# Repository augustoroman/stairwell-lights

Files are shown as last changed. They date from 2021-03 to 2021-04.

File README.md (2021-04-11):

# Motion-Activated Stairwell Lights

This project uses [addressable LED
strips](https://components101.com/displays/neopixel-led-strip), two [PIR motion
sensors](https://learn.adafruit.com/pir-passive-infrared-proximity-motion-sensor),
and [a microcontroller](https://www.sparkfun.com/products/13231) to make some
motion-activated stair lighting with some cool light-up animations.

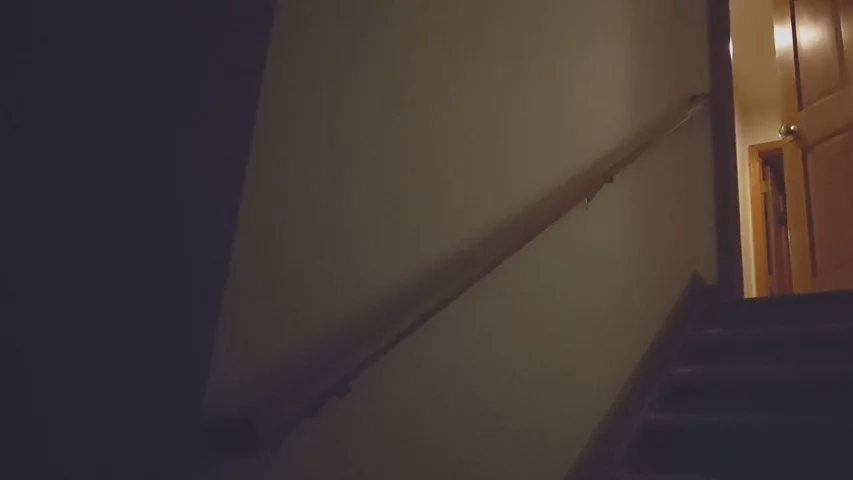
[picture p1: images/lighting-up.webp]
Lighting up


# How it works

The basic setup is:

Overview Schematic

The stairwell turns 90°, so there are two LED strips: the upper and the lower.
Similarly, there are two PIR motion sensors: the upper (looking upwards) and the
lower (looking downwards).

The LED strips and motion sensores are plugged into an ESP8266 housed in a 3D
printed box:

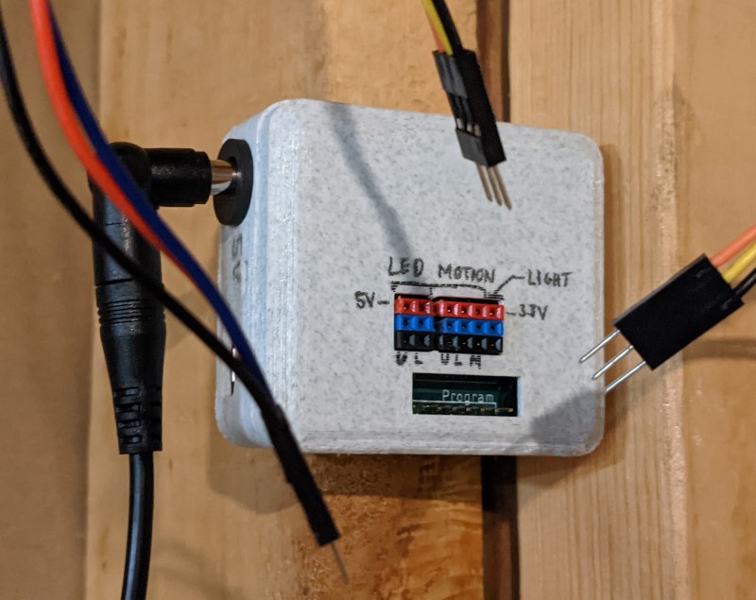
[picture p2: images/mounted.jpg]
Mounted controller box


Within the box is the microcontroller along with a simple custom PCB that routes
the wiring:

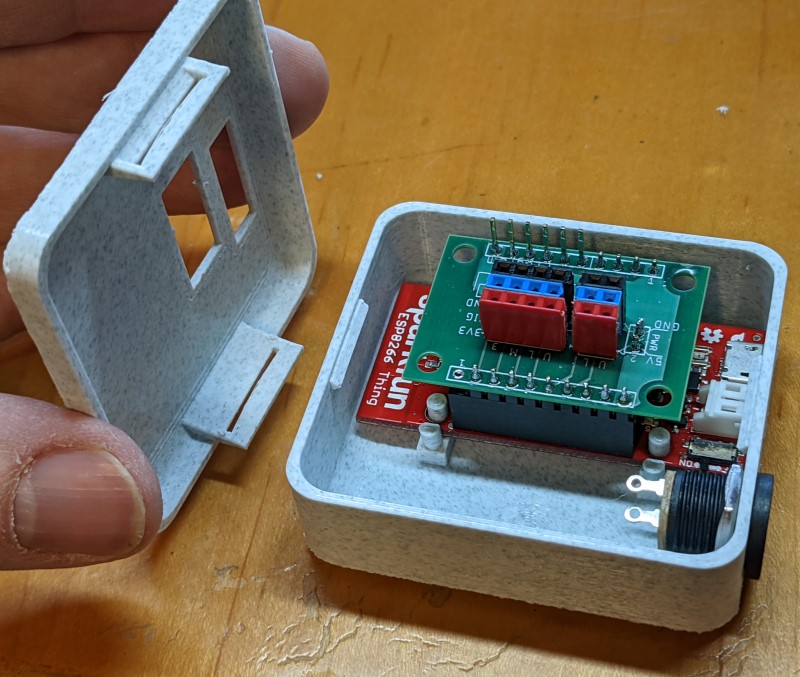
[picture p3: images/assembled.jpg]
Inside controller box


The custom PCB by itself:

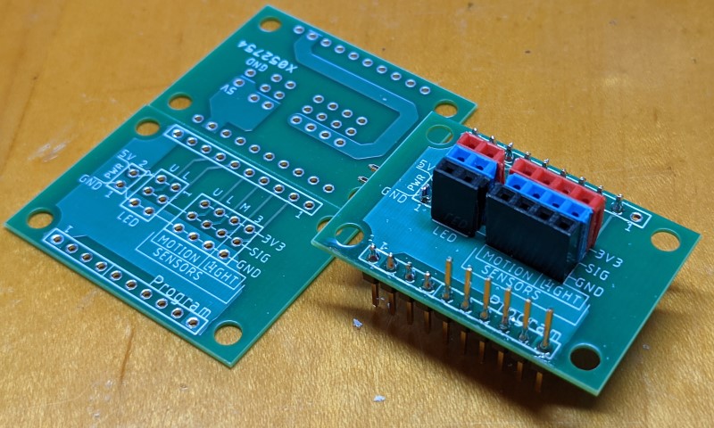
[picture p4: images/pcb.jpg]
Custom PCB


# Materials

### Core Materials

* A 5m string of **WS2812B lights** with an adhesive backing
  [[Amazon](https://www.amazon.com/gp/product/B01CDTEJBG)] <br> The important
  characteristics of this strip are:
  * WS2812B lights are relatively cheap but still individually addressable so
    that each LED is individually controlled.
  * 5V lights makes it easier to integrate with the microcontroller.
  * I used 60 LEDs/m density to balance smooth lighting with power usage.
    Probably 30 LEDs/m would work just about as well.
  * They have adhesive backing so I can just stick them straight to the bottom
    of the handrail.
* **PIR sensors** (2x) [[Amazon](https://www.amazon.com/gp/product/B08PVB7VHQ/)]
  <br> The important characteristics of these are:
  * They come with connector pins already (easy to integrate) and are about the
    size I wanted.
  * They are open-collector that ground the sensor line, so they work with 5V or
    3.3V.
  * They have 3 - 5m range, which worked well for my stairwell.
* An **ESP8266 microcontroller** [[Sparkfun](https://www.sparkfun.com/products/13231)]
  <br> I happened to have one of these microcontrollers lying around, but most
  Arduino or ESP boards should work. The important characteristics are:
  * It has at least 4 digital I/O pins.
  * It automatically handles 5V -> 3.3V conversions.
  * It's small and fairly cheap.
  * It has Wifi built-in, which is great for upcoming features I want to add.
  * It also has analog inputs that I want to use for upcoming features (a light
    sensor).

### Custom items

Some custom manufactured items:

* [A PCB](./connector-pcb) that allows simple wiring between the ESP8266 pins and the wiring to the
  LED strips and sensors.

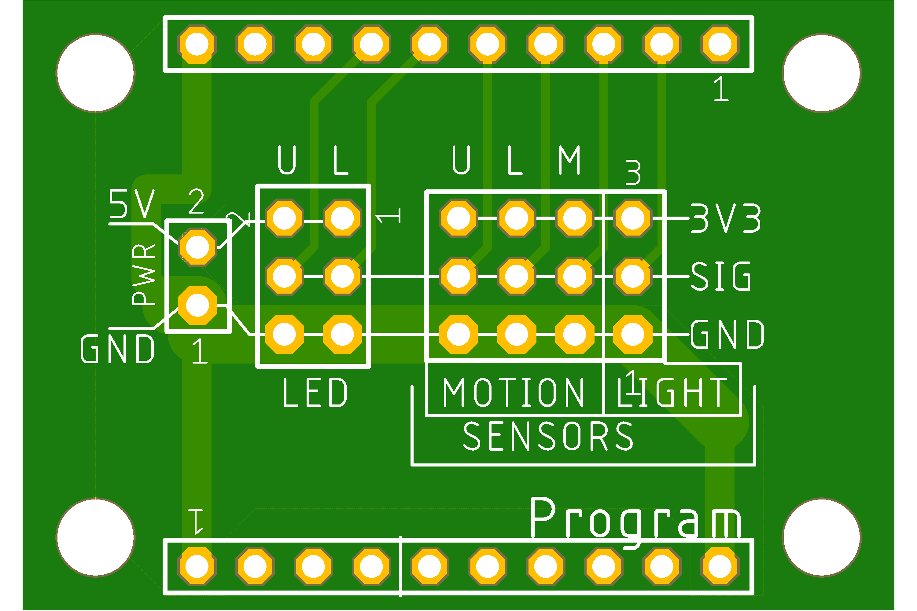
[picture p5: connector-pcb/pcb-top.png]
  
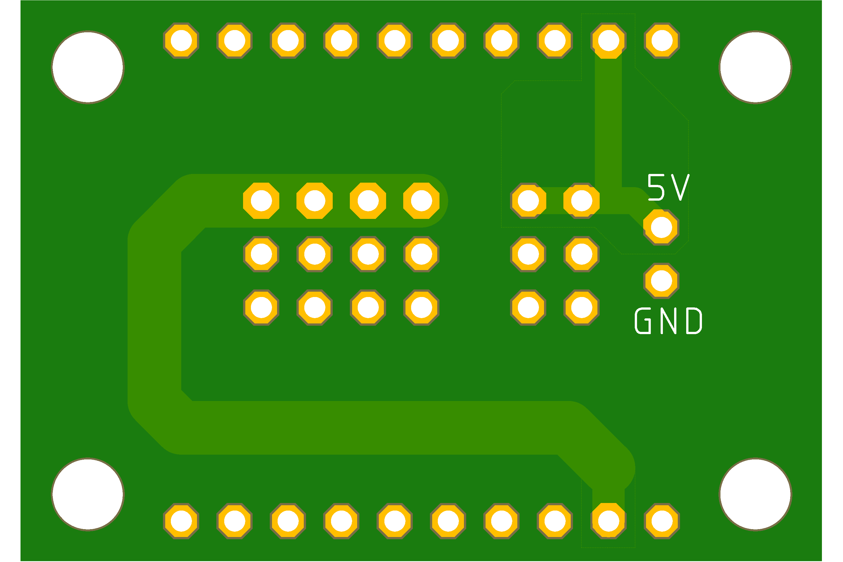
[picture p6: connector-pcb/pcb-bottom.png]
  

  This was manufactured using basicpcb.com which can create this 1.5" x 1.05"
  board for only ~$2.50 each! With a min quantity of 3, that's only ~$8 for the
  board (including shipping!).

* Several [3D-printed items](./3dprint): case ([top](./3dprint/case-top.stl),
  [bottom](./3dprint/case-bottom.stl)) and [PIR sensor
  mount](./3dprint/pir-holder.stl).

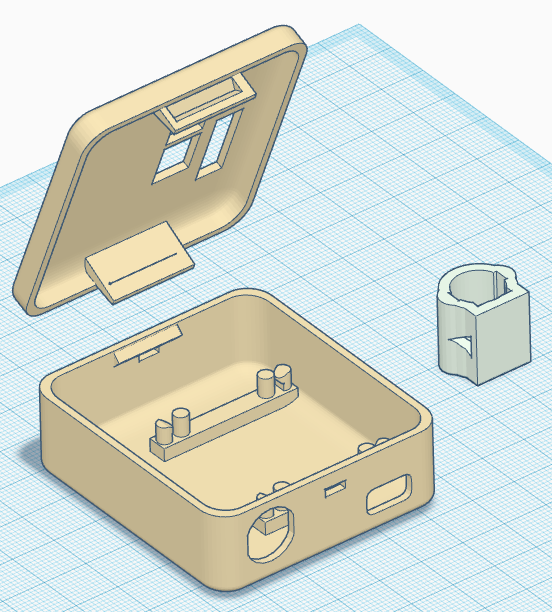
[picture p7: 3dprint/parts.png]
  

### Miscellaneous Materials

Those are the core of the whole setup, but there's lots of additional things I
needed to actually complete the setup:

* **Colorful headers** [[Adafruit](https://www.adafruit.com/product/4160)] <br>
  I used these nice colorful headers so it's obvious which way to connect the
  strips since I used plain headers instead of polarized connectors. Probably I
  should have used polarized connectors, but that would probably require a PCB
  change.
* A panel-mount **DC barrel jack connector**
  [[Adafruit](https://www.adafruit.com/product/610)]
* **LED strip connectors** [[Amazon](https://www.amazon.com/gp/product/B08NX8TN8C)]
  <br> I originally tried soldering wires to the LED strips, but changed from
  the small-gauge hookup wire to the thicker 20-gauge wire and used these
  connectors instead. I glue-gunned the connector to the bottom of the railing.
* A **5V DC power supply**. The current software draws 0.25A idle and 0.5A
  maximum current draw from the power supply (2.5W max), so this [5W power
  supply](https://smile.amazon.com/dp/B08Q38QMFD) or this [10W power
  supply](https://smile.amazon.com/dp/B0863J9RLW) should work fine and provide
  plenty of buffer.  I'm currently using [a generic
  supply](https://www.amazon.com/gp/product/B078LSVVTB) for development.
* **20 AWG solid-core hookup wire** to connect the LEDs
  [[Amazon](https://www.amazon.com/gp/product/B083DNGSPV)] <br> The LEDs can use
  a surprising amount of power (up to 90W for the whole strip!!), and really
  thin-guage wire may melt. The program I have runs the LEDs only at very dim
  settings, so we're not maximing out the power draw and the 20 gauge wire
  should be sufficient.
* **22 AWG hookup wire** to connect the motion sensors
  [[Amazon](https://www.amazon.com/gp/product/B088KQFHV7)] <br> You can use the
  20 gauge wire too, but I had this thinner wire around for the low-power
  sensors.
* A **crimper and connectors**
  [[Amazon](https://www.amazon.com/gp/product/B07R1H3Z8X)] to make clean
  connections to/from the microcontroller. <br> I used the XH-2A connectors for
  power with short 18-AWG wire, but that was a tight fit.

# Changes I would make if I did this again

- [ ] I'd use a board-mounted DC jack instead of a panel-mounted one and modify
  the PCB to use that. That means I'd have to extend the board a bit (a few more
  $), but connecting the board to the panel-mount DC jack was a pain.
- [ ] I'd probably space out the connectors some and use polarized connectors.
- [ ] The 3D printed case could use quite a bit of tweaking to tight up the
  tolerances.
  - [x] The opening for the programming headers was shifted to the side.
    I've fixed that in the tinkercad version but not the STLs here.
  - [ ] The snaps that hold the board are too loose -- the board snaps in
    tightly but then wiggles around.
  - [ ] The top and bottom fit together too loosely.
  - [ ] I'd try to 3D print labels on the case directly, maybe even try to
    change filament colors so they look nice. If not changing colors, at least I
    could color the raised labels.

# Features I want to add to the software

- [ ] Add wifi control and save setting to EEPROM
  - [ ] On initial boot (or when it cannot connect to wifi), start an access
    point and webserver and allow configuring the board with wifi creds.
  - [ ] When connected to wifi, allow configuring the length of each LED string
    rather than having that hard-coded.
  - [ ] Track history of when the lights were triggered and provided via the web
    server so I can be sure it's not triggering spuriously all night long.
  - [ ] Fun: Add LED test mode where a slider control turns on a single LED and
    you can watch it slide back and forth.
  - [ ] Control the "on" color of the lights via the web server. Can
    bright/dim/colorize the lights this way, but watch out! Making the LEDs too
    bright might draw too much power.
- [ ] Add [a light sensor](https://www.sparkfun.com/products/8688) to disable
  the lights when it's already bright. The connection is easy and the connector
  board already planned for this, but picking thresholds is hard. I want the web
  server up and running first.
- [ ] Maybe add a middle motion sensor that looks at the landing. Right now the
  landing is not visible from either the upper or lower sensors, but it's not a
  problem.

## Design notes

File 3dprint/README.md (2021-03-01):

# 3D printed parts

I designed and printed many test parts for this project but ultimately used 3 of
them:

* A holder for the PIR sensors I used.
* The top and bottom case for the microcontroller and DC jack.

In this directory I've included the STL files for these parts. The [original
design was done in tinkercad](https://www.tinkercad.com/things/i8FOYjX7VH2).

Parts
Assembed

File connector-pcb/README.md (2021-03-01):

# Connector PCB

This PCB was designed to plug into a [SparkFun ESP8266
Thing](https://www.sparkfun.com/products/13231).





It was designed in the [free version of Autodesk's Eagle
CAD](https://www.autodesk.com/products/eagle/free-download).

I had this manufactured by basicpcb.com which was very cheap and fast: it cost
about $15 since I paid an extra $8 for quick shipping and I received the board
in 8 calendar days.

Included is the original [stairwell.brd](./stairwell.brd) file, but I've also
included the [gerber zip file](./stairwell_2021-02-15.zip) that can be directly
uploaded to basicpcb.

The board dimensions are 1.5" x 1.05".

Here's the file to layer mapping:

file                   | layer
-----------------------|-------------------
copper_bottom.gbr      | Bottom Copper
copper_top.gbr         | Top Copper
drill_1_16.xln         | NC Drill
gerber_job.gbrjob      | Drawing/Other
profile.gbr            | Drawing/Other
silkscreen_bottom.gbr  | Bottom Silkscreen
silkscreen_top.gbr     | Top Silkscreen
soldermask_bottom.gbr  | Bottom Soldermask
soldermask_top.gbr     | Top Soldermask
solderpaste_bottom.gbr | Bottom Solderpaste
solderpaste_top.gbr    | Top Solderpaste

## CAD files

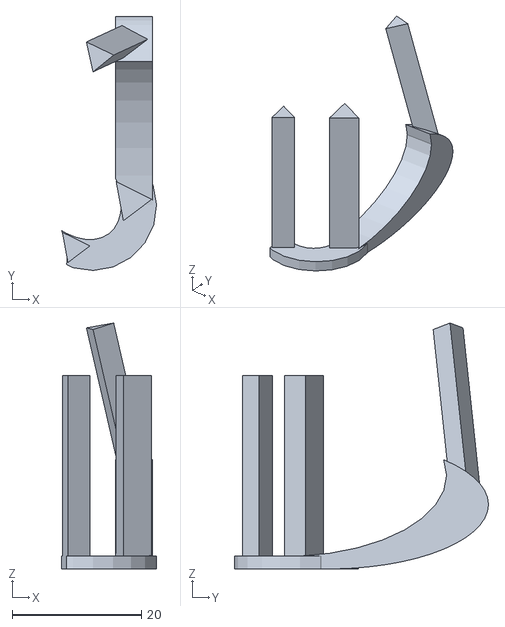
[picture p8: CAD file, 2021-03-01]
3dprint/pir-holder.stl
14.7 x 39.3 x 38.1

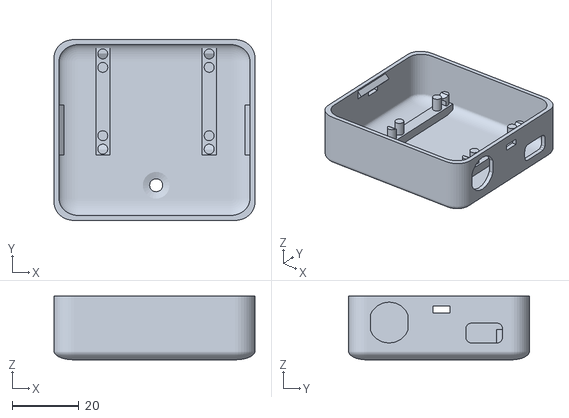
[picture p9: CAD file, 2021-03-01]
3dprint/case-bottom.stl
60.0 x 54.0 x 19.0

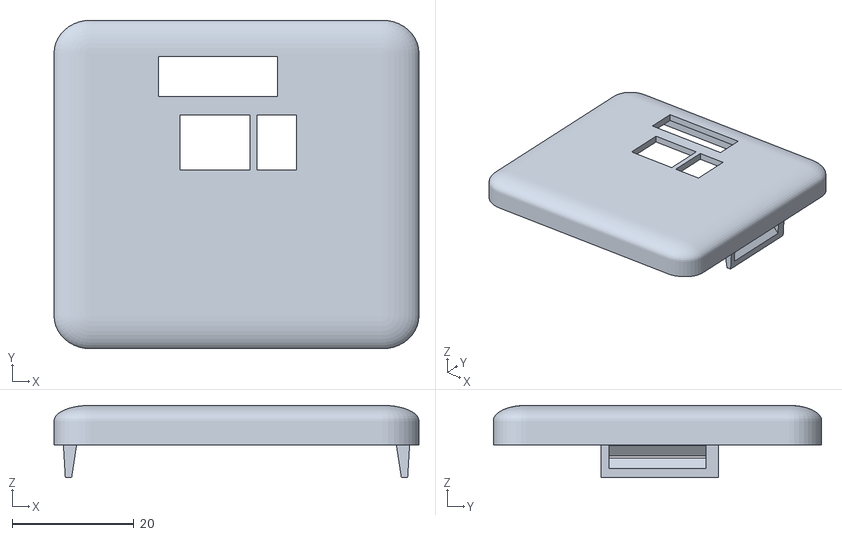
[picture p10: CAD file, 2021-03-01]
3dprint/case-top.stl
60.0 x 54.0 x 11.9

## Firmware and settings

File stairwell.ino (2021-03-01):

#include <FastLED.h>

const int LOWER_STRIP_PIN = 4;
const int UPPER_STRIP_PIN = 0;
const int LOWER_STRIP_COUNT = 73;
const int UPPER_STRIP_COUNT = 167;
const int NUM_LEDS = UPPER_STRIP_COUNT + LOWER_STRIP_COUNT;

const int LOWER_MOTION_PIN = 12; // Pin connected to motion detector
const int UPPER_MOTION_PIN = 13; // Pin connected to motion detector

// LED is pin 13 on the blackboard, but pin 5 on the thing
// const int BOARD_LED_PIN = 13; // Blackboard LED pin - active-high
const int BOARD_LED_PIN = 5; // Thing LED pin - active-high

const int STEP_MS = 10;
const int STEP_OVERHEAD = 7;
const int TIMEOUT_MS = 10000;
const int TIMEOUT_STEPS = TIMEOUT_MS / (STEP_MS + STEP_OVERHEAD);
const int DIM_MS = 5000;
const int DIM_STEPS = DIM_MS / (STEP_MS + STEP_OVERHEAD);

const int FADE_WIDTH = 40;
const int MAX_BRIGHTNESS = 80;
const CHSV ON_COLOR = CHSV(20, 160, 255);

CRGB leds[NUM_LEDS];

struct State {
  // bool indicating whether the strip should be brightening or dimming.
  bool upper_triggered;
  int upper_pos;

  bool lower_triggered;
  int lower_pos;

  int steps_since_last_triggered;
  int current_max_brightness;
  bool dimming;
};

State state;

uint8_t brightness[NUM_LEDS];
void clearBrightness(int val) {
  for (int i = 0; i < NUM_LEDS; i++) {
    brightness[i] = val;
  }
}
void brightenSmoothRegion(int start, int stop, int border, int fullOn) {
  int midpoint = (start + stop)/2;

  int i = start < 0 ? 0 : start;
  for (; i < NUM_LEDS && i < start+border && i < midpoint; i++) {
    int target = (i - start) * fullOn / border;
    if (brightness[i] < target) {
      brightness[i] = target;
    }
  }
  for (; i < NUM_LEDS && i < stop-border; i++) {
    brightness[i] = fullOn;
  }
  for (; i < NUM_LEDS && i < stop; i++) {
    int target = (stop - i) * fullOn / border;
    if (brightness[i] < target) {
      brightness[i] = target;
    }
  }
}
void setBrightnessToLEDS() {
  // reverse the lower strip
  for (int i = 0; i < LOWER_STRIP_COUNT; i++) {
    // leds[LOWER_STRIP_COUNT - 1 - i] = ON_COLOR;
    // leds[LOWER_STRIP_COUNT - 1 - i].fadeToBlackBy(256-brightness[i]);
    leds[LOWER_STRIP_COUNT - 1 - i].setHSV(ON_COLOR.hue, ON_COLOR.sat, brightness[i]);
  }
  // Keep upper strip in order
  for (int i = LOWER_STRIP_COUNT; i < NUM_LEDS; i++) {
    // leds[i] = ON_COLOR;
    // leds[i].fadeToBlackBy(256-brightness[i]);
    leds[i].setHSV(ON_COLOR.hue, ON_COLOR.sat, brightness[i]);
  }
}

void resetState() {
  state.upper_triggered = false;
  state.upper_pos = NUM_LEDS;
  state.lower_triggered = false;
  state.lower_pos = 0;
  state.steps_since_last_triggered = 0;
  state.current_max_brightness = MAX_BRIGHTNESS; 
  state.dimming = false;
}

void setup() {
  // put your setup code here, to run once:
  FastLED.addLeds<NEOPIXEL, LOWER_STRIP_PIN>(leds, 0, LOWER_STRIP_COUNT);
  FastLED.addLeds<NEOPIXEL, UPPER_STRIP_PIN>(leds, LOWER_STRIP_COUNT, UPPER_STRIP_COUNT);

  pinMode(LOWER_MOTION_PIN, INPUT);
  pinMode(UPPER_MOTION_PIN, INPUT);
  pinMode(BOARD_LED_PIN, OUTPUT);

  resetState();
}

void loop() {
  bool hasLowerMotion = !!digitalRead(LOWER_MOTION_PIN);
  bool hasUpperMotion = !!digitalRead(UPPER_MOTION_PIN);
  // bool hasLowerMotion = (int(millis() / 1000ul) % 20) == 0;
  // bool hasUpperMotion = false;

  update(&state, hasLowerMotion, hasUpperMotion);
  FastLED.show();

  bool led = (state.upper_triggered || state.lower_triggered) && !state.dimming; 
  digitalWrite(BOARD_LED_PIN, led ? HIGH : LOW);
  delay(STEP_MS);
}

void step(struct State *s) {
  if (s->upper_triggered || s->lower_triggered) {
    s->steps_since_last_triggered++;

    s->dimming = s->steps_since_last_triggered > TIMEOUT_STEPS;

    if (s->dimming) {
      dimToOff(s);
    } else {
      brightenToOn(s);
    }
  }
  // upper_triggered && lower_triggered may have been reset by dimToOff().
  if (s->upper_triggered && s->upper_pos > -FADE_WIDTH) {
    s->upper_pos--;
  }
  if (s->lower_triggered && s->lower_pos < NUM_LEDS+FADE_WIDTH) {
    s->lower_pos++;
  }
  clearBrightness(0);
  // brightenSmoothRegion(LOWER_STRIP_COUNT-16, LOWER_STRIP_COUNT-1, 5, s->current_max_brightness);
  // brightenSmoothRegion(LOWER_STRIP_COUNT-26, LOWER_STRIP_COUNT-20, 5, s->current_max_brightness);
  brightenSmoothRegion(-FADE_WIDTH, s->lower_pos, FADE_WIDTH, s->current_max_brightness);
  brightenSmoothRegion(s->upper_pos, NUM_LEDS+FADE_WIDTH, FADE_WIDTH, s->current_max_brightness);
  setBrightnessToLEDS();
}

void turnOnLower(struct State *s) {
  s->steps_since_last_triggered = 0;
  if (!s->lower_triggered) {
    s->lower_triggered = true;
    s->lower_pos = 0;
  }
}
void turnOnUpper(struct State *s) {
  s->steps_since_last_triggered = 0;
  if (!s->upper_triggered) {
    s->upper_triggered = true;
    s->upper_pos = NUM_LEDS;
  }
}

void dimToOff(struct State *s) {
  auto num_dimming_steps = s->steps_since_last_triggered - TIMEOUT_STEPS;
  s->current_max_brightness = MAX_BRIGHTNESS - num_dimming_steps * MAX_BRIGHTNESS / DIM_STEPS;
  if (s->current_max_brightness < 0) {
    resetState();    
  }
}
void brightenToOn(struct State *s) {
  if (s->current_max_brightness < MAX_BRIGHTNESS) {
    s->current_max_brightness++;
  }
}

void update(struct State *s, bool hasLowerMotion, bool hasUpperMotion) {
  if (hasUpperMotion) {
    turnOnUpper(s);
  }
  if (hasLowerMotion) {
    turnOnLower(s);
  }
  step(s);
}

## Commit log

2021-03-01 Initial working version.
    This version has:
    - Two light strips (upper and lower)
    - Two sensors (upper and lower)
    When motion is detected from either sensor, it begins lighting up the
    stairwell from that end. If both sensors are triggered, it will light
    up from both ends.
2021-03-01 Add the PCB EAGLE files.
    This is the definition of the custom board that I designed and had
    manufactured by basicpcb.com.
    I included the zip file that I uploaded directly to basicpcb, so others
    that want to manufacture this board need only to use the provided zip.
    [stairwell.brd]
2021-03-01 Add 3d printing files
    [case-bottom.stl, case-top.stl, pir-holder.stl]
2021-04-11 Update README with measure power draw.
    Measured to use 0.25A idle (1.25W) and 0.5A full on (2.5W).
    This is well below the maximum power draw of the LEDs and seems
    consistent with the fact that we're keeping the LEDs really dim. I intend
    to order at least a 10W power supply to give plenty of buffer for
    tinkering with the software in the future.
